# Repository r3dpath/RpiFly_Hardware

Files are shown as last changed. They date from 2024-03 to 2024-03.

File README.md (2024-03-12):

### RpiFly V3 Hardware

While most of the functionality here has been tested to work theres certainally some marginal design decisions, just beware.





Cone Launch Altitude

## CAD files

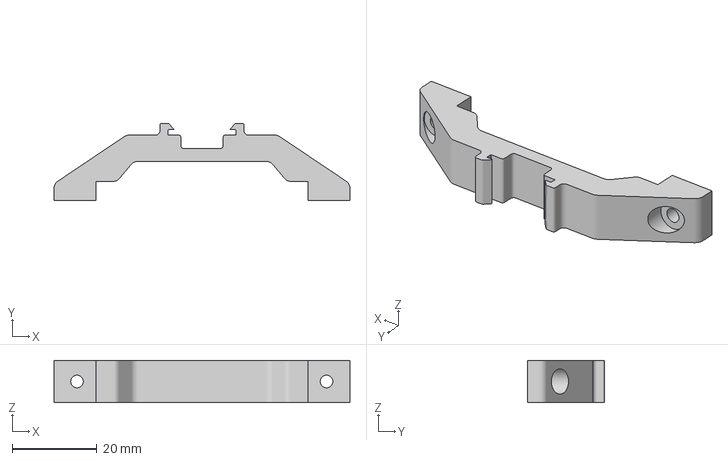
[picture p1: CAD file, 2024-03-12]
RpiFly v3/nrf24 clip v3.3mf
70.0 x 18.3 x 10.0 mm

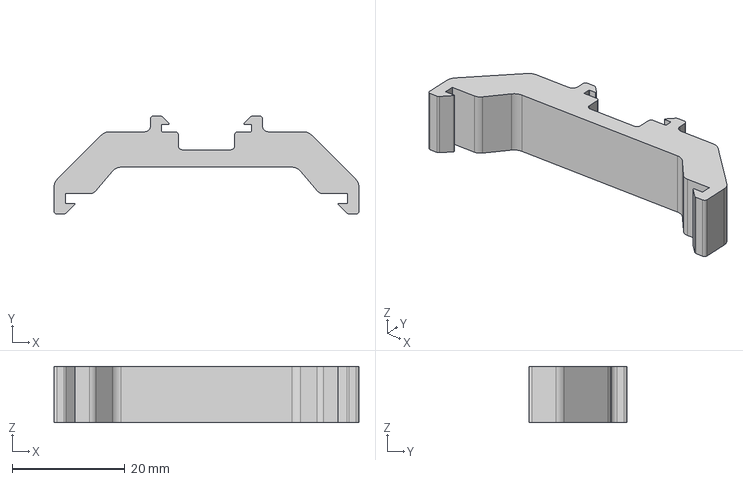
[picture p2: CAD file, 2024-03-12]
RpiFly v3/nrf24 clip v1.step
54.2 x 17.4 x 10.0 mm

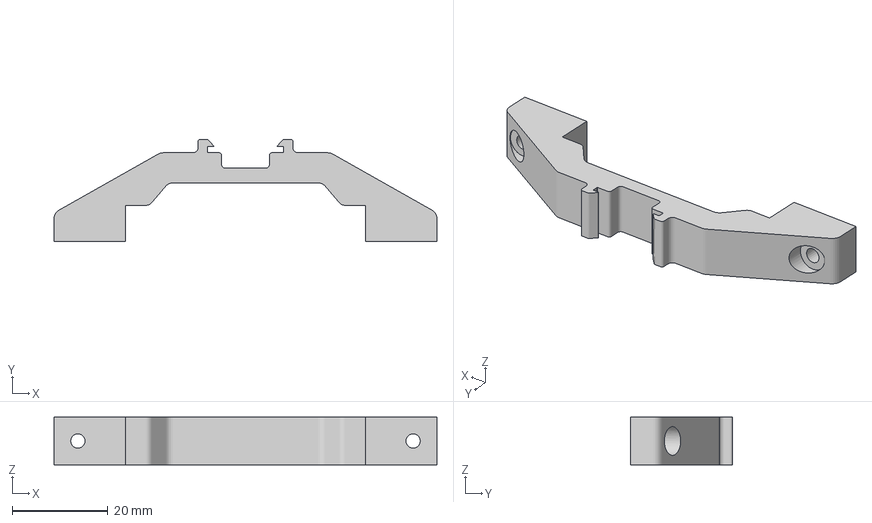
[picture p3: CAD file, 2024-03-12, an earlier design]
RpiFly v3/nrf24 clip v2.3mf
80.2 x 21.4 x 10.0 mm

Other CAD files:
RpiFly v3/nrf24 clip v1.3mf

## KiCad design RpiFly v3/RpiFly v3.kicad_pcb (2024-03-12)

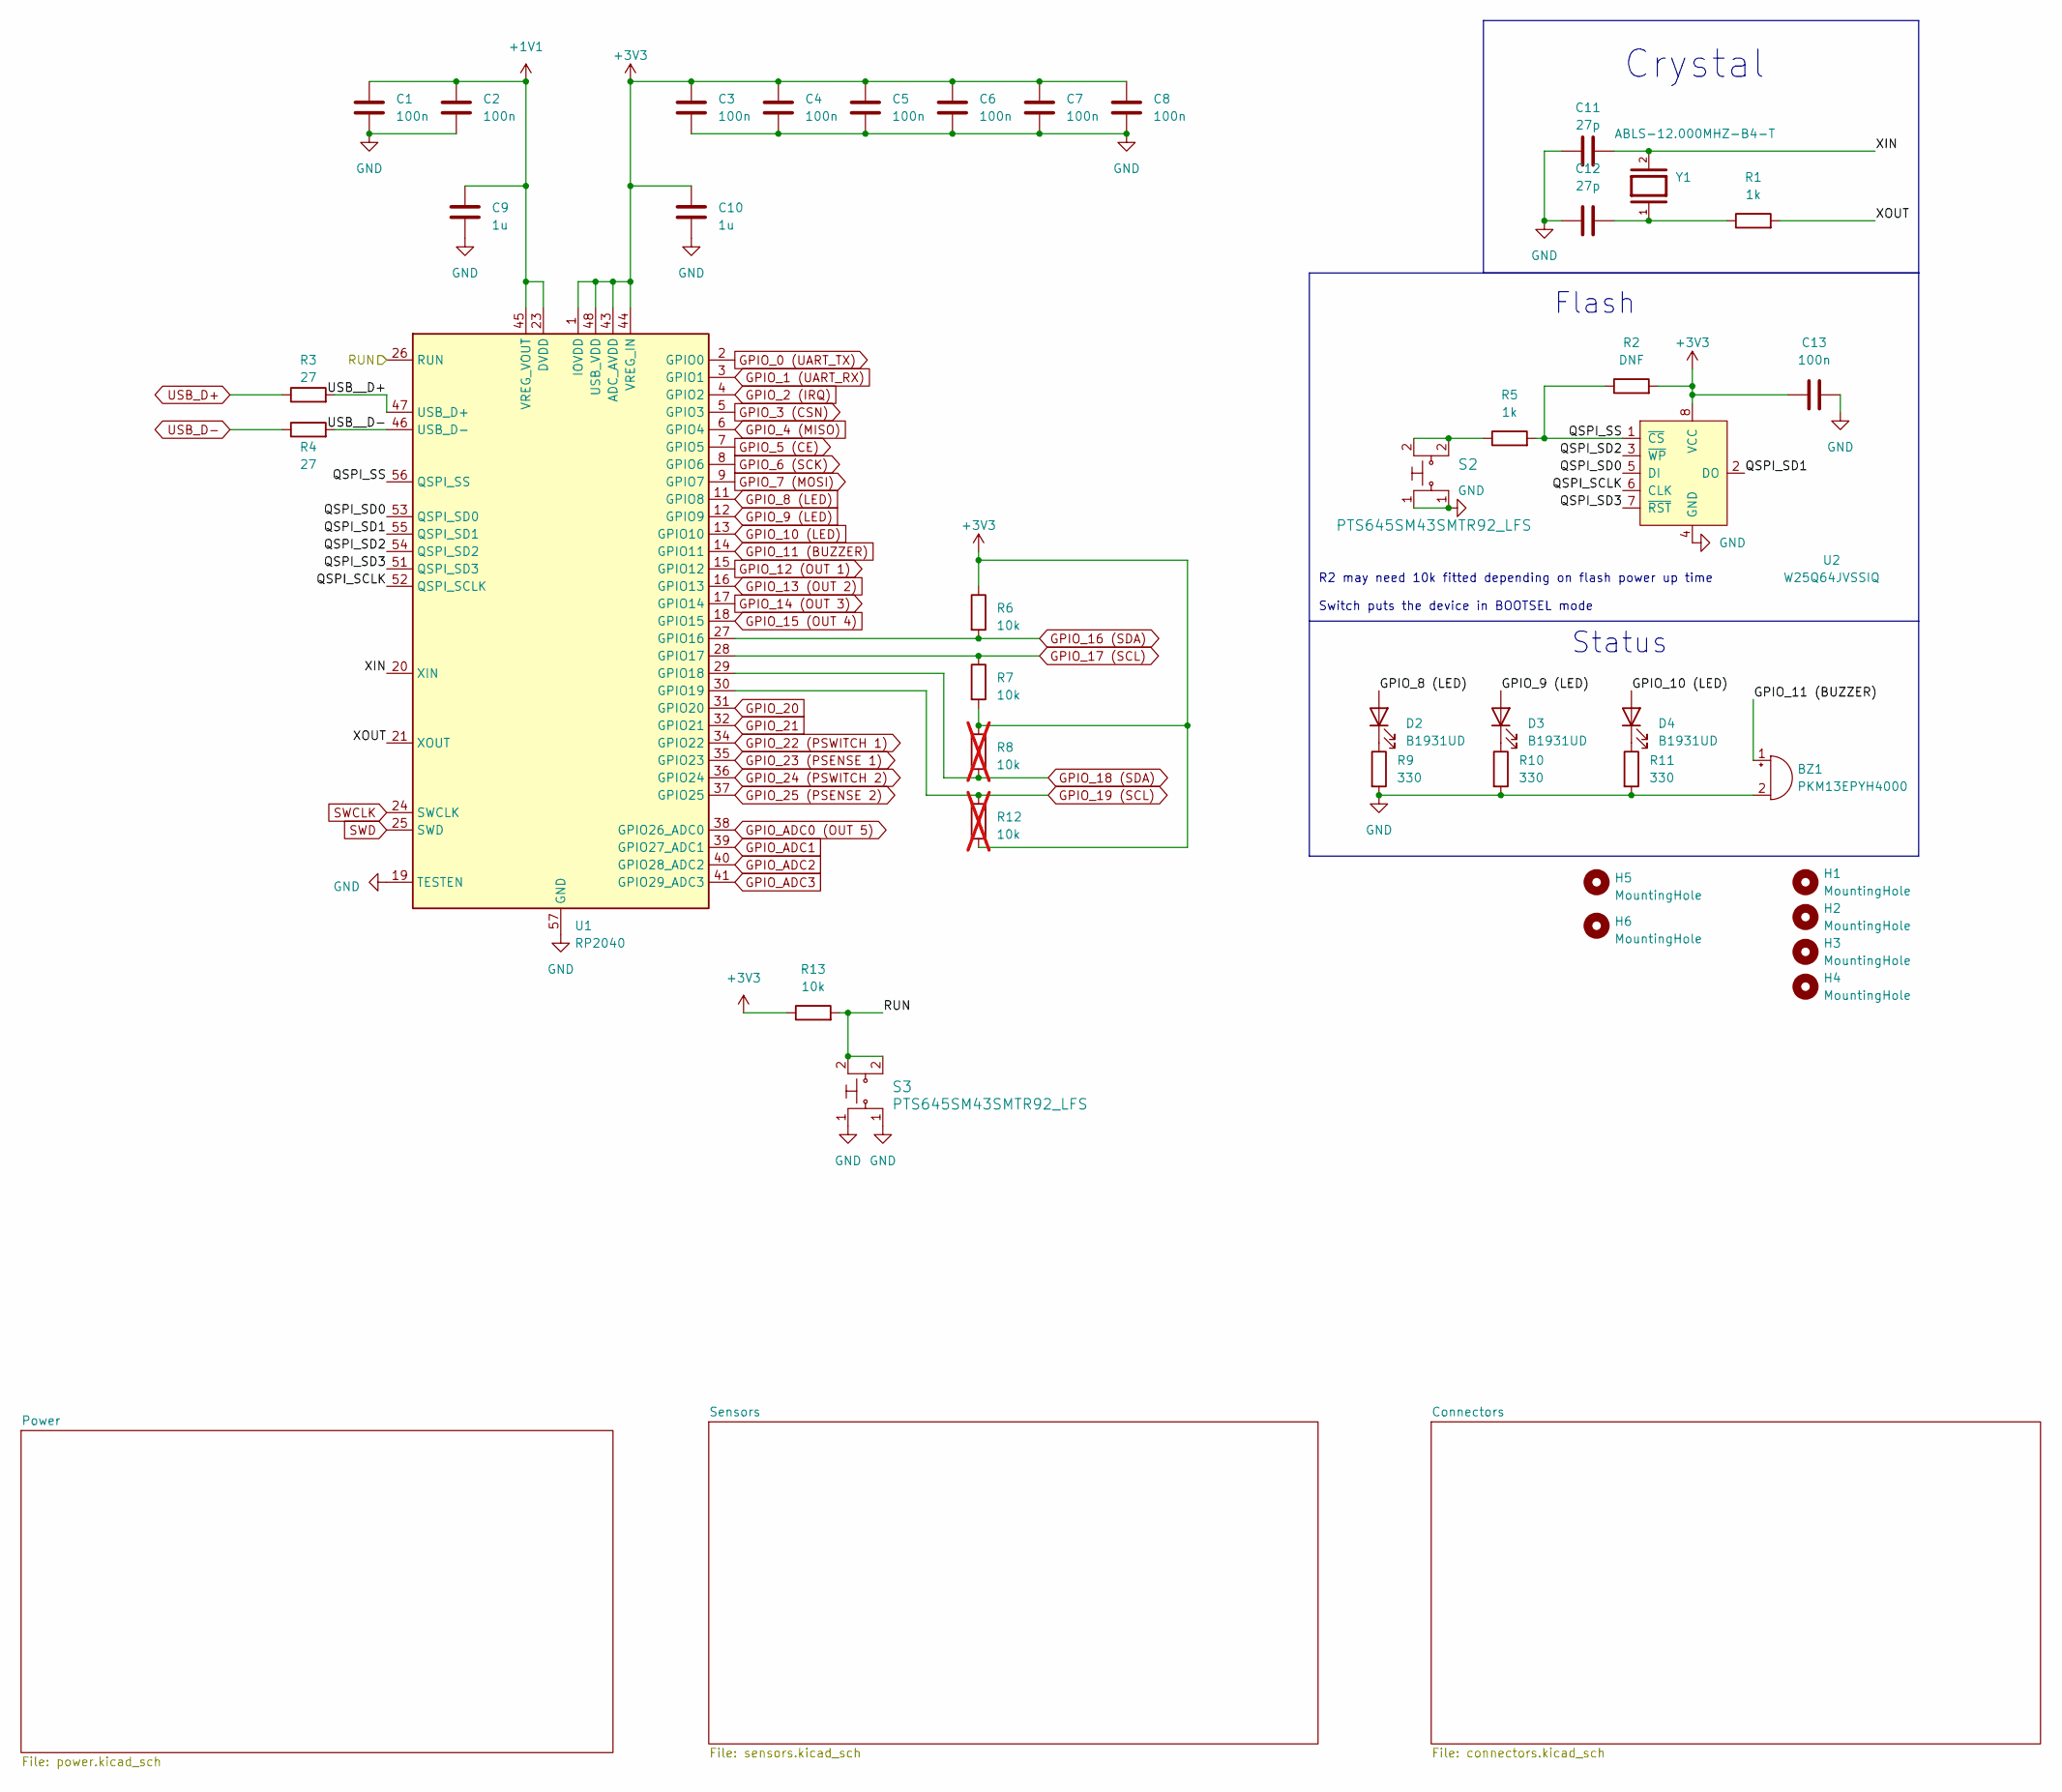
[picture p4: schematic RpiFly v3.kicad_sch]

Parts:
BZ1: PKM13EPYH4000
C1, C2, C3, C4, C5, C6, C7, C8, C13: 100n; C_0603_1608Metric
C9, C10: 1u; C_0603_1608Metric
C11, C12: 27p; C_0603_1608Metric
D2, D3, D4: B1931UD; LED_0603_1608Metric
H1, H2, H3, H4: MountingHole; MountingHole_3.2mm_M3_Pad_Via
H5, H6: MountingHole; MountingHole_1.1mm_M1_Pad
R1, R5: 1k; R_0603_1608Metric
R2: DNF; R_0603_1608Metric
R3, R4: 27; R_0603_1608Metric
R6, R7, R13: 10k; R_0603_1608Metric
R8, R12: 10k; R_0603_1608Metric; not fitted
R9, R10, R11: 330; R_0603_1608Metric
S2, S3: PTS645SM43SMTR92_LFS; SW_Push_1P1T_NO_6x6mm_H9.5mm; MPN PTS645SM43SMTR92 LFS; Digi-Key_PN CKN9112CT-ND
U1: RP2040; QFN-56-1EP_7x7mm_P0.4mm_EP3.2x3.2mm
U2: W25Q64JVSSIQ; SOIC-8_5.23x5.23mm_P1.27mm; MPN W25Q32JVSSIQ TR; Digi-Key_PN W25Q32JVSSIQCT-ND
Y1: ABLS-12.000MHZ-B4-T; Crystal_SMD_HC49-SD; PARTREV 02.16.2021

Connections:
+1V1: C1.1, C2.1, C9.1, U1.23 (DVDD), U1.45 (VREG_VOUT), U1.50 (DVDD)
+3V3: C3.1, C4.1, C5.1, C6.1, C7.1, C8.1, C10.1, C13.1, R2.2, R6.1, R7.2, R8.1, R12.2, R13.1, U1.1 (IOVDD), U1.10 (IOVDD), U1.22 (IOVDD), U1.33 (IOVDD), U1.42 (IOVDD), U1.43 (ADC_AVDD), U1.44 (VREG_IN), U1.48 (USB_VDD), U1.49 (IOVDD), U2.8 (VCC); also elsewhere on the board
/QSPI_SCLK: U1.52 (QSPI_SCLK), U2.6 (CLK)
/QSPI_SD0: U1.53 (QSPI_SD0), U2.5 (DI)
/QSPI_SD1: U1.55 (QSPI_SD1), U2.2 (DO)
/QSPI_SD2: U1.54 (QSPI_SD2), U2.3 (~WP)
/QSPI_SD3: U1.51 (QSPI_SD3), U2.7 (~RST)
/QSPI_SS: R2.1, R5.2, U1.56 (QSPI_SS), U2.1 (~CS)
/RUN: R13.2, S3.2, U1.26 (RUN)
/USB__D+: R3.2, U1.47 (USB_D+)
/USB__D-: R4.2, U1.46 (USB_D-)
/XIN: C11.2, U1.20 (XIN), Y1.2
/XOUT: R1.2, U1.21 (XOUT)
GND: BZ1.2 (+), C1.2, C2.2, C3.2, C4.2, C5.2, C6.2, C7.2, C8.2, C9.2, C10.2, C11.1, C12.2, C13.2, H1.1, H2.1, R9.2, R10.2, R11.2, S2.1, S3.1, U1.19 (TESTEN), U1.57 (GND), U2.4 (GND); also elsewhere on the board
GPIO_0 (UART_TX): U1.2 (GPIO0); also elsewhere on the board
GPIO_1 (UART_RX): U1.3 (GPIO1); also elsewhere on the board
GPIO_2 (IRQ): U1.4 (GPIO2); also elsewhere on the board
GPIO_3 (CSN): U1.5 (GPIO3); also elsewhere on the board
GPIO_4 (MISO): U1.6 (GPIO4); also elsewhere on the board
GPIO_5 (CE): U1.7 (GPIO5); also elsewhere on the board
GPIO_6 (SCK): U1.8 (GPIO6); also elsewhere on the board
GPIO_7 (MOSI): U1.9 (GPIO7); also elsewhere on the board
GPIO_8 (LED): D2.2 (A), U1.11 (GPIO8)
GPIO_9 (LED): D3.2 (A), U1.12 (GPIO9)
GPIO_10 (LED): D4.2 (A), U1.13 (GPIO10)
GPIO_11 (BUZZER): BZ1.1 (-), U1.14 (GPIO11)
GPIO_12 (OUT 1): U1.15 (GPIO12); also elsewhere on the board
GPIO_13 (OUT 2): U1.16 (GPIO13); also elsewhere on the board
GPIO_14 (OUT 3): U1.17 (GPIO14); also elsewhere on the board
GPIO_15 (OUT 4): U1.18 (GPIO15); also elsewhere on the board
GPIO_16 (SDA): R6.2, U1.27 (GPIO16); also elsewhere on the board
GPIO_17 (SCL): R7.1, U1.28 (GPIO17); also elsewhere on the board
GPIO_18 (SDA): R8.2, U1.29 (GPIO18); also elsewhere on the board
GPIO_19 (SCL): R12.1, U1.30 (GPIO19); also elsewhere on the board
GPIO_20: U1.31 (GPIO20)
GPIO_21: U1.32 (GPIO21)
GPIO_22 (PSWITCH 1): U1.34 (GPIO22); also elsewhere on the board
GPIO_23 (PSENSE 1): U1.35 (GPIO23); also elsewhere on the board
GPIO_24 (PSWITCH 2): U1.36 (GPIO24); also elsewhere on the board
GPIO_25 (PSENSE 2): U1.37 (GPIO25); also elsewhere on the board
GPIO_ADC0 (OUT 5): U1.38 (GPIO26_ADC0); also elsewhere on the board
GPIO_ADC1: U1.39 (GPIO27_ADC1)
GPIO_ADC2: U1.40 (GPIO28_ADC2)
GPIO_ADC3: U1.41 (GPIO29_ADC3)
unnamed: C12.1, R1.1, Y1.1
unnamed: D2.1 (K), R9.1
unnamed: D3.1 (K), R10.1
unnamed: D4.1 (K), R11.1
unnamed: R5.1, S2.2
SWCLK: U1.24 (SWCLK); also elsewhere on the board
SWD: U1.25 (SWD); also elsewhere on the board
USB_D+: R3.1; also elsewhere on the board
USB_D-: R4.1; also elsewhere on the board

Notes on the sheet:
R2 may need 10k fitted depending on flash power up time Switch puts the device in BOOTSEL mode
Flash
Crystal
Status

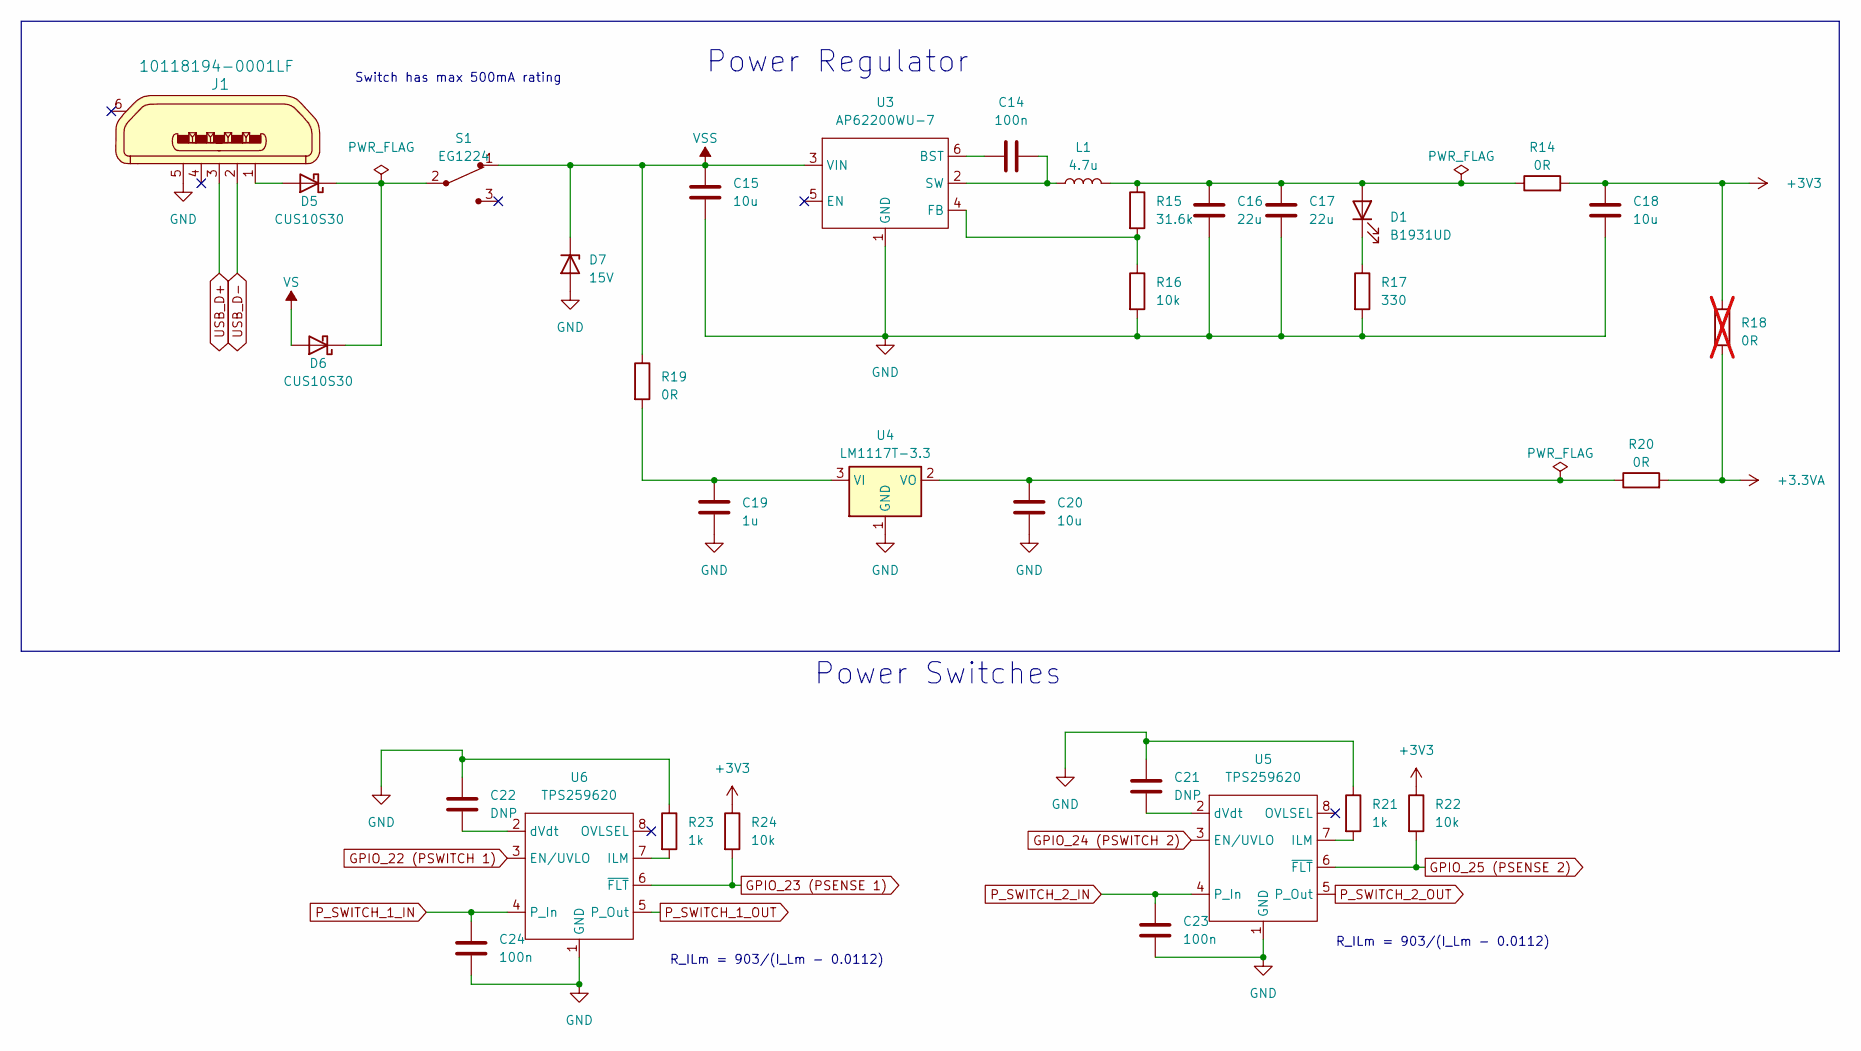
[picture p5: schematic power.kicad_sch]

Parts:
C14, C23, C24: 100n; C_0603_1608Metric
C15, C18, C20: 10u; C_0603_1608Metric
C16, C17: 22u; C_0603_1608Metric
C19: 1u; C_0603_1608Metric
C21, C22: DNP; C_0603_1608Metric
D1: B1931UD; D_0603_1608Metric
D5, D6: CUS10S30; D_SOD-323
D7: 15V; D_DO-41_SOD81_P7.62mm_Horizontal
J1: 10118194-0001LF; USB_Micro-B_Amphenol_10118194_Horizontal; MPN 10118194-0001LF; Digi-Key_PN 609-4618-1-ND
L1: 4.7u; L_Taiyo-Yuden_NR-60xx
R14, R19, R20: 0R; R_0603_1608Metric
R15: 31.6k; R_0603_1608Metric
R16, R22, R24: 10k; R_0603_1608Metric
R17: 330; R_0603_1608Metric
R18: 0R; R_0603_1608Metric; not fitted
R21, R23: 1k; R_0603_1608Metric
S1: EG1224; SW_E-Switch_EG1224_SPDT_Angled; MPN EG1218; Digi-Key_PN EG1903-ND
U3: AP62200WU-7; TSOT-23-6
U4: LM1117T-3.3; TO-220-3_Horizontal_TabDown
U5, U6: TPS259620; Texas_R-PDSO-G8_EP2.95x4.9mm_Mask2.4x3.1mm_ThermalVias

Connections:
+3.3VA: R18.2, R20.2; also elsewhere on the board
+3V3: C18.1, R14.2, R18.1, R22.1, R24.1; also elsewhere on the board
GND: C15.1, C16.2, C17.2, C18.2, C19.2, C20.2, C21.1, C22.1, C23.2, C24.2, D7.2 (A), J1.5, R16.2, R17.2, R21.1, R23.1, U3.1 (GND), U4.1 (GND), U5.1 (GND), U6.1 (GND); also elsewhere on the board
GPIO_22 (PSWITCH 1): U6.3 (EN/UVLO); also elsewhere on the board
GPIO_23 (PSENSE 1): R24.2, U6.6 (~FLT); also elsewhere on the board
GPIO_24 (PSWITCH 2): U5.3 (EN/UVLO); also elsewhere on the board
GPIO_25 (PSENSE 2): R22.2, U5.6 (~FLT); also elsewhere on the board
unnamed: C16.1, C17.1, D1.2 (A), L1.2, R14.1, R15.1
unnamed: D1.1 (K), R17.1
unnamed: D5.2 (A), J1.1
unnamed: D5.1 (K), D6.1 (K), S1.2
unnamed: C14.1, U3.6 (BST)
unnamed: R15.2, R16.1, U3.4 (FB)
unnamed: C14.2, L1.1, U3.2 (SW)
unnamed: C19.1, R19.2, U4.3 (VI)
unnamed: C20.1, R20.1, U4.2 (VO)
unnamed: R21.2, U5.7 (ILM)
unnamed: C21.2, U5.2 (dVdt)
unnamed: R23.2, U6.7 (ILM)
unnamed: C22.2, U6.2 (dVdt)
P_SWITCH_1_IN: C24.1, U6.4 (P_In); also elsewhere on the board
P_SWITCH_1_OUT: U6.5 (P_Out); also elsewhere on the board
P_SWITCH_2_IN: C23.1, U5.4 (P_In); also elsewhere on the board
P_SWITCH_2_OUT: U5.5 (P_Out); also elsewhere on the board
USB_D+: J1.3; also elsewhere on the board
USB_D-: J1.2; also elsewhere on the board
VS: D6.2 (A); also elsewhere on the board
VSS: C15.2, D7.1 (K), R19.1, S1.1, U3.3 (VIN)

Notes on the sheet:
Switch has max 500mA rating
Power Switches
R_ILm = 903/(I_Lm - 0.0112)
Power Regulator

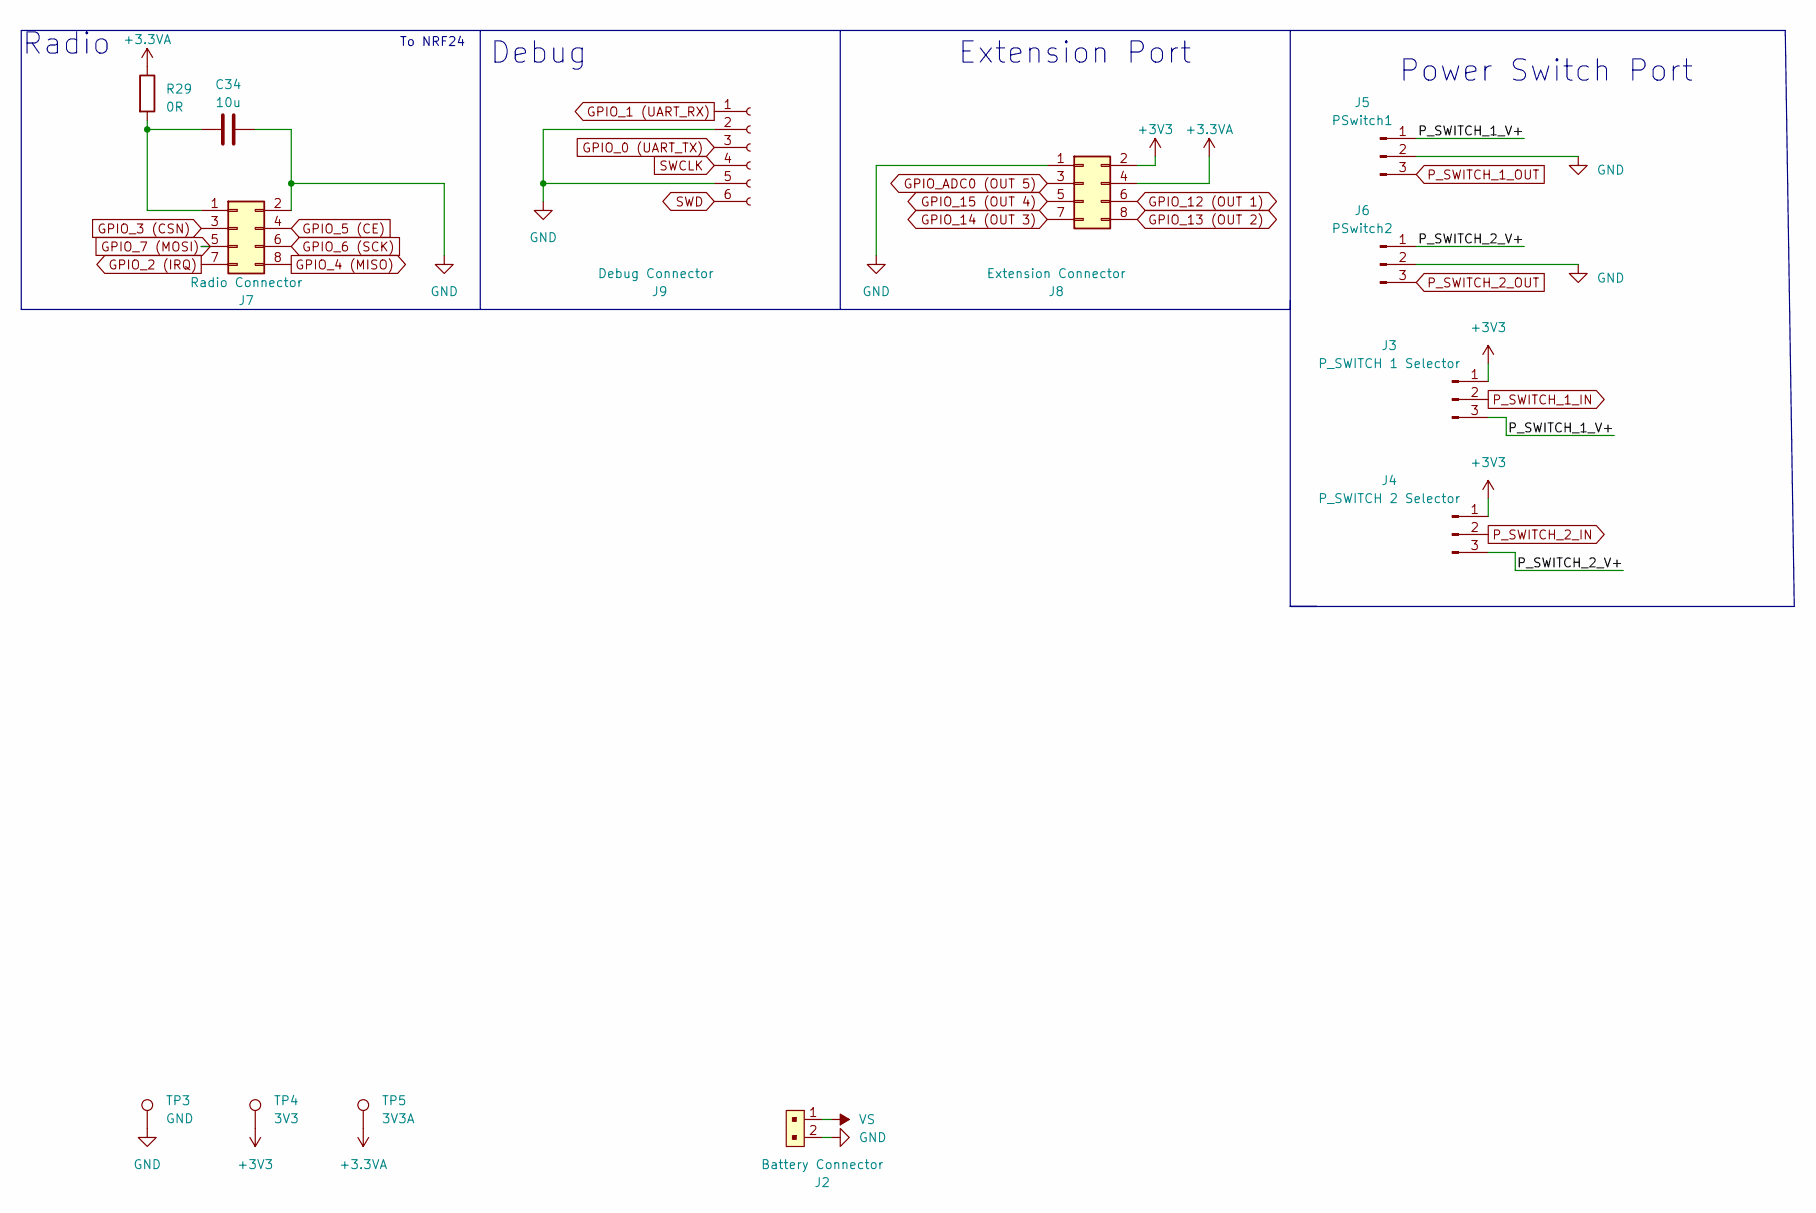
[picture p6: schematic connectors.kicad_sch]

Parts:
C34: 10u; C_0603_1608Metric
J2: Battery Connector; JST_PH_S2B-PH-K_1x02_P2.00mm_Horizontal
J3: P_SWITCH 1 Selector; PinHeader_1x03_P2.54mm_Vertical
J4: P_SWITCH 2 Selector; PinHeader_1x03_P2.54mm_Vertical
J5: PSwitch1; JST_PH_S3B-PH-K_1x03_P2.00mm_Horizontal
J6: PSwitch2; JST_PH_S3B-PH-K_1x03_P2.00mm_Horizontal
J7: Radio Connector; PinSocket_2x04_P2.54mm_Vertical
J8: Extension Connector; PinSocket_2x04_P2.54mm_Vertical
J9: Debug Connector; JST_SH_SM06B-SRSS-TB_1x06-1MP_P1.00mm_Horizontal
R29: 0R; R_0603_1608Metric
TP3: GND; TestPoint_Pad_D1.0mm
TP4: 3V3; TestPoint_Pad_D1.0mm
TP5: 3V3A; TestPoint_Pad_D1.0mm

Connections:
+3.3VA: J8.4, R29.1, TP5.1; also elsewhere on the board
+3V3: J3.1, J4.1, J8.2, TP4.1; also elsewhere on the board
/Connectors/P_SWITCH_1_V+: J3.3, J5.1
/Connectors/P_SWITCH_2_V+: J4.3, J6.1
GND: C34.2, J2.2, J5.2, J6.2, J7.2, J8.1, J9.2, J9.5, TP3.1; also elsewhere on the board
GPIO_0 (UART_TX): J9.3; also elsewhere on the board
GPIO_1 (UART_RX): J9.1; also elsewhere on the board
GPIO_2 (IRQ): J7.7; also elsewhere on the board
GPIO_3 (CSN): J7.3; also elsewhere on the board
GPIO_4 (MISO): J7.8; also elsewhere on the board
GPIO_5 (CE): J7.4; also elsewhere on the board
GPIO_6 (SCK): J7.6; also elsewhere on the board
GPIO_7 (MOSI): J7.5; also elsewhere on the board
GPIO_12 (OUT 1): J8.6; also elsewhere on the board
GPIO_13 (OUT 2): J8.8; also elsewhere on the board
GPIO_14 (OUT 3): J8.7; also elsewhere on the board
GPIO_15 (OUT 4): J8.5; also elsewhere on the board
GPIO_ADC0 (OUT 5): J8.3; also elsewhere on the board
unnamed: C34.1, J7.1, R29.2
P_SWITCH_1_IN: J3.2; also elsewhere on the board
P_SWITCH_1_OUT: J5.3; also elsewhere on the board
P_SWITCH_2_IN: J4.2; also elsewhere on the board
P_SWITCH_2_OUT: J6.3; also elsewhere on the board
SWCLK: J9.4; also elsewhere on the board
SWD: J9.6; also elsewhere on the board
VS: J2.1; also elsewhere on the board

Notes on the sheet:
Extension Port
Power Switch Port
Radio
Debug
To NRF24

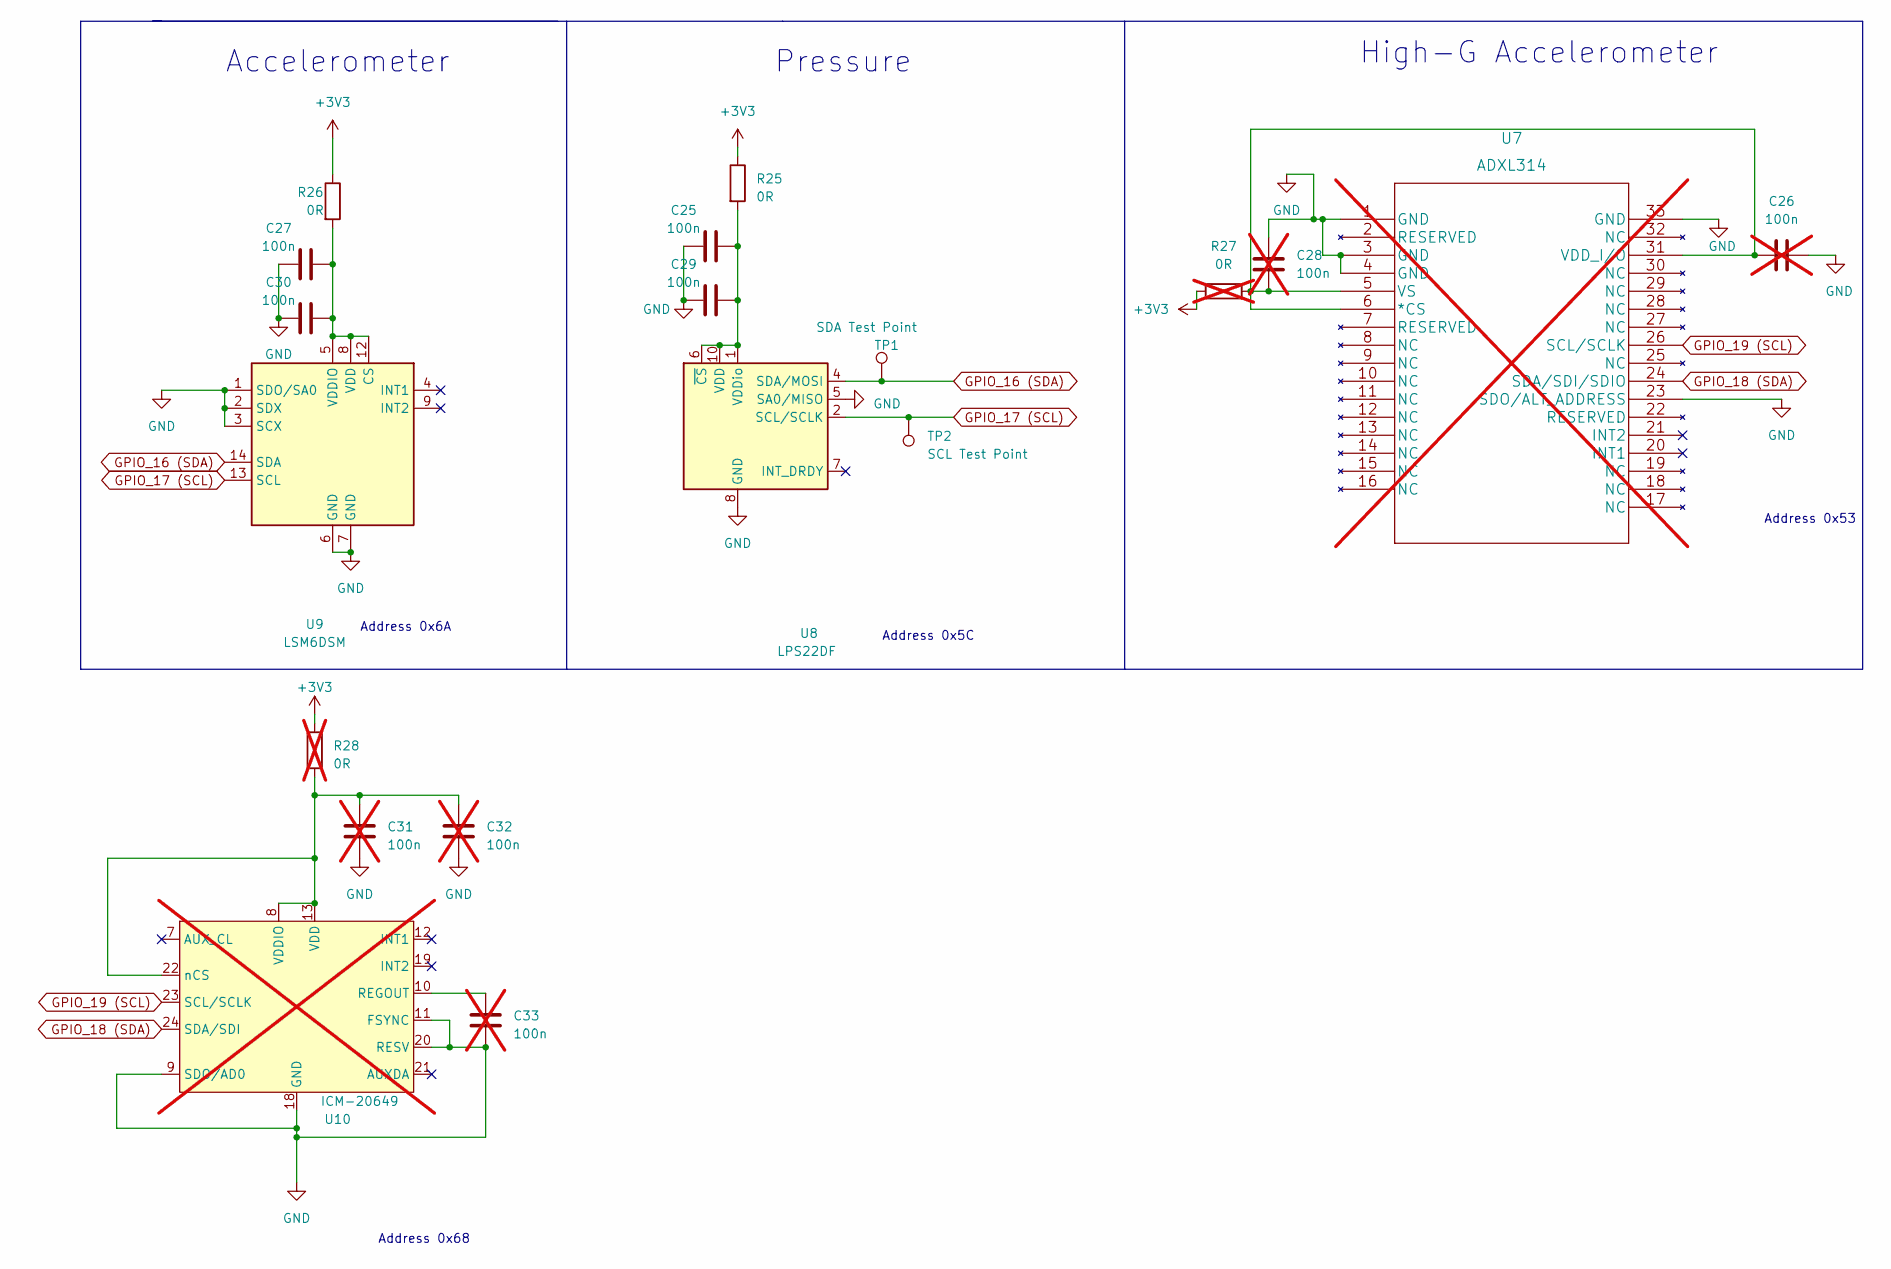
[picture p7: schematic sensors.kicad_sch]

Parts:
C25, C27, C29, C30: 100n; C_0603_1608Metric
C26, C28, C31, C32, C33: 100n; C_0603_1608Metric; not fitted
R25, R26: 0R; R_0603_1608Metric
R27, R28: 0R; R_0603_1608Metric; not fitted
TP1: SDA Test Point; TestPoint_Pad_D1.0mm
TP2: SCL Test Point; TestPoint_Pad_D1.0mm
U7: ADXL314; LFCSP-32-1EP_5x5mm_P0.5mm_EP3.6x3.6mm; not fitted
U8: LPS22DF; ST_HLGA-10_2.5x2.5mm_P0.6mm_LayoutBorder3x2y
U9: LSM6DSM; LGA-14_3x2.5mm_P0.5mm_LayoutBorder3x4y
U10: ICM-20649; QFN-24-1EP_3x3mm_P0.4mm_EP1.75x1.6mm; not fitted

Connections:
+3V3: R25.1, R26.1, R27.1, R28.1; also elsewhere on the board
GND: C25.1, C26.2, C27.1, C28.1, C29.1, C30.1, C31.2, C32.1, C33.2, U7.1 (GND), U7.3 (GND), U7.4 (GND), U7.23 (SDO/ALT_ADDRESS), U7.33 (GND), U8.3 (GND), U8.5 (SA0/MISO), U8.8 (GND), U8.9 (GND), U9.1 (SDO/SA0), U9.2 (SDX), U9.3 (SCX), U9.6 (GND), U9.7 (GND), U10.9 (SDO/AD0), U10.11 (FSYNC), U10.18 (GND), U10.20 (RESV); also elsewhere on the board
GPIO_16 (SDA): TP1.1, U8.4 (SDA/MOSI), U9.14 (SDA); also elsewhere on the board
GPIO_17 (SCL): TP2.1, U8.2 (SCL/SCLK), U9.13 (SCL); also elsewhere on the board
GPIO_18 (SDA): U7.24 (SDA/SDI/SDIO), U10.24 (SDA/SDI); also elsewhere on the board
GPIO_19 (SCL): U7.26 (SCL/SCLK), U10.23 (SCL/SCLK); also elsewhere on the board
unnamed: C26.1, C28.2, R27.2, U7.5 (VS), U7.6 (*CS), U7.31 (VDD_I/O)
unnamed: C25.2, C29.2, R25.2, U8.1 (VDDio), U8.6 (~CS), U8.10 (VDD)
unnamed: C27.2, C30.2, R26.2, U9.5 (VDDIO), U9.8 (VDD), U9.12 (CS)
unnamed: C33.1, U10.10 (REGOUT)
unnamed: C31.1, C32.2, R28.2, U10.8 (VDDIO), U10.13 (VDD), U10.22 (nCS)

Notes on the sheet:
Accelerometer
High-G Accelerometer
Pressure
Address 0x53
Address 0x68
Address 0x6A
Address 0x5C

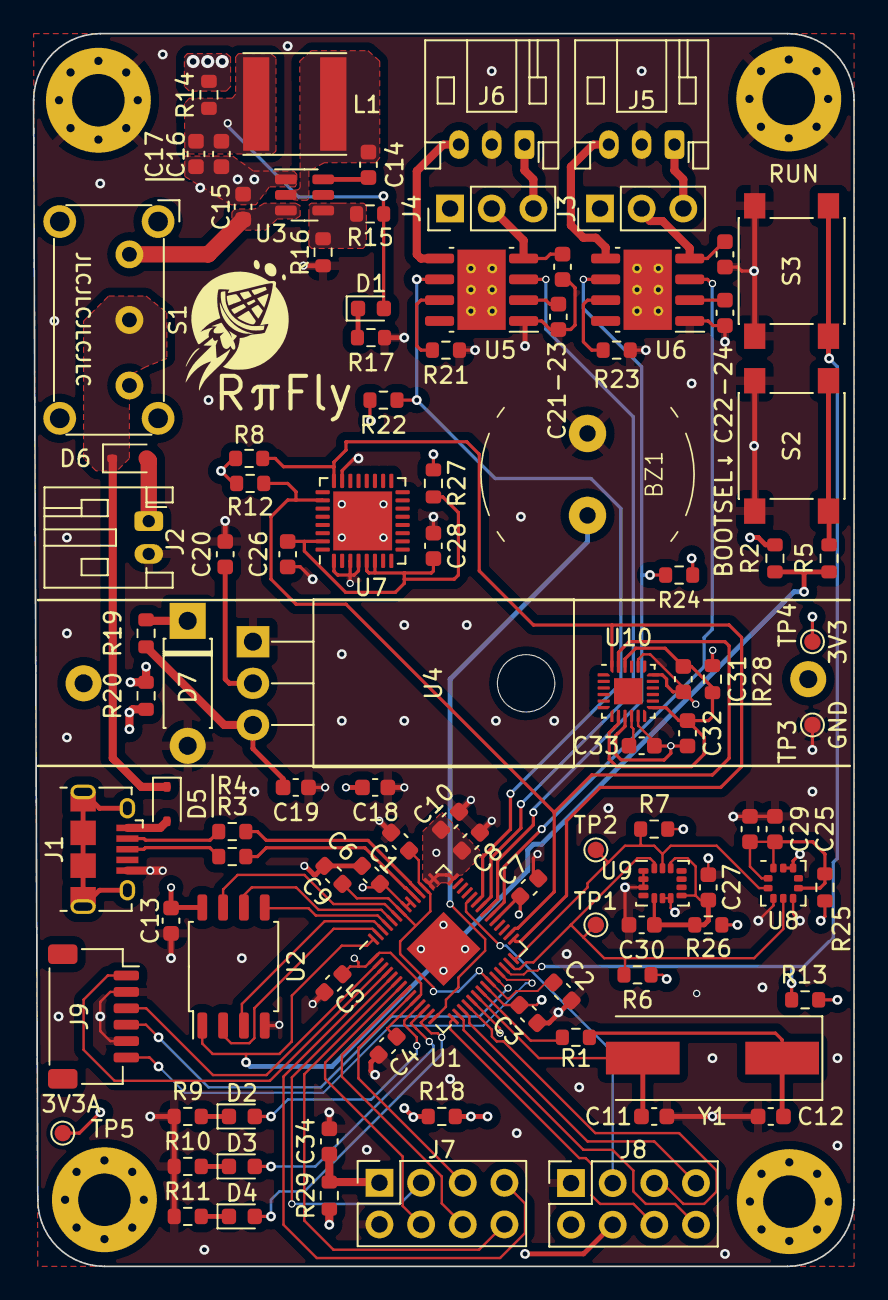
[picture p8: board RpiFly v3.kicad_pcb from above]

Board: 4 copper layers, 50.0 x 75.2 mm, 106 parts (1 on the bottom side), 76 nets.
